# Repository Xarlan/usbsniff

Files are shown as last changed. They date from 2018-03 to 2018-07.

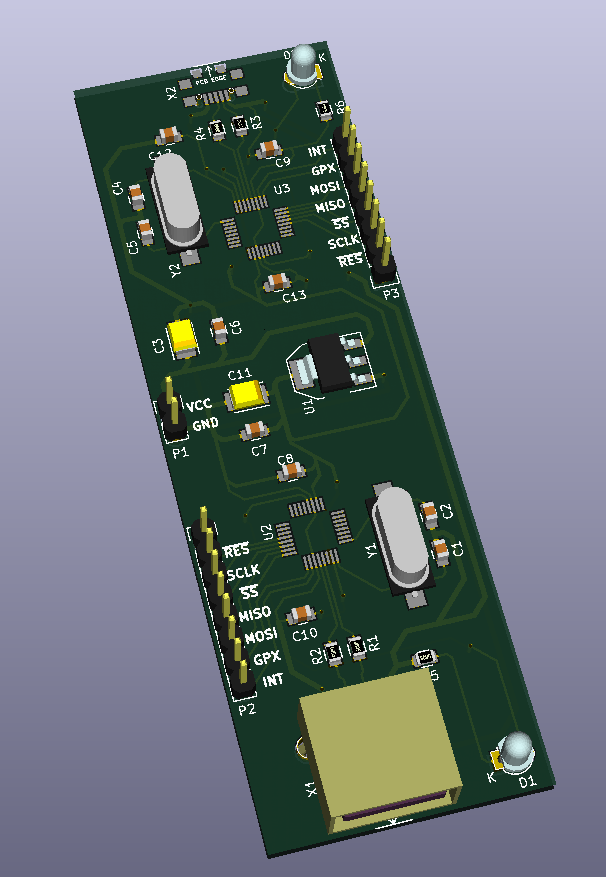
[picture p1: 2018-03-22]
prototype3.png

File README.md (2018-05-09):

# usbsniff
Develop hardware usb 2.0 sniffer

The main idea - to develop cheap hardware usb sniffer which possible to assemble at home :)

Current version based on MAX3421E

/pcb

This folder contain KiCad project of usb sniffer

## Limitation

Support follow EP:
* EP0: CONTROL (64 bytes)
* EP1: OUT, BULK or INTERRUPT
* EP2: IN, BULK or INTERRUPT
* EP3: IN, BULK or INTERRUPT

Thank you for "x8-999-github" for some good advices and idea.

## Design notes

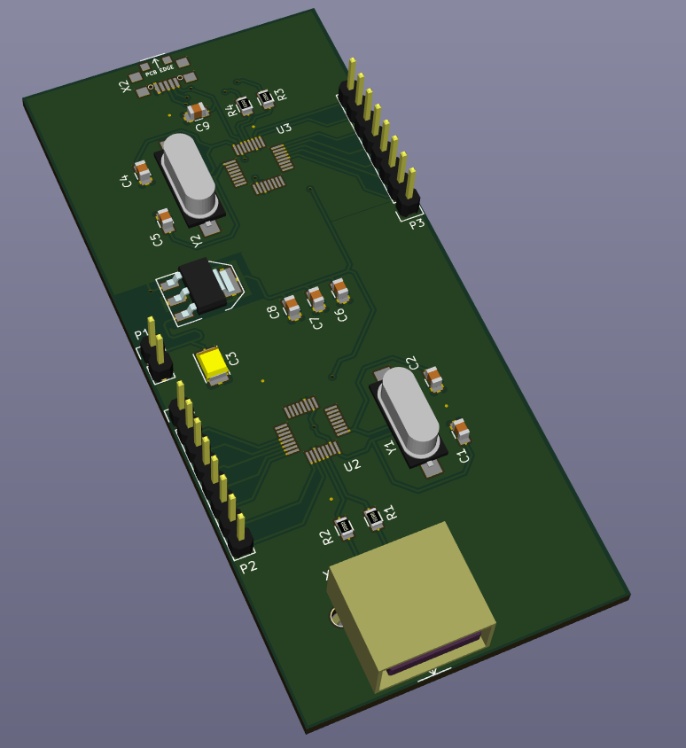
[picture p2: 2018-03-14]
prototype.png

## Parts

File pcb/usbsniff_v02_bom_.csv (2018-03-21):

Component | Description | Part | References | Value | Footprint | Quantity Per PCB | Datasheet
1 | Unpolarized capacitor | C_Small | C6 C7 C8 C13 | 0.1uF | C_0805 | 4
2 | Polarised capacitor | CP_Small | C3 C11 | 10uF | TantalC_SizeB_EIA-3528_Reflow | 2
3 | Unpolarized capacitor | C_Small | C9 C10 C12 | 1uF | C_0805 | 3
4 | Unpolarized capacitor | C_Small | C1 C2 C4 C5 | 20pF | C_0805 | 4
5 |  | LED | D1 D2 | LED | LED-3MM | 2
6 | Connector 01x02 | CONN_01X02 | P1 | CONN_01X02 | Pin_Header_Straight_1x02 | 1
7 | Connector 01x08 | CONN_01X08 | P2 P3 | CONN_01X08 | Pin_Header_Straight_1x08 | 2
8 | Resistor | R_Small | R1 R2 R3 R4 | 33 Ohm | R_0805 | 4
9 | Resistor | R | R5 R6 | 470 Ohm | R_0805 | 2
10 | Adjustable/Fixed Low Dropout Linear Regulator | AMS1117 | U1 | AMS1117 | SOT-223 | 1
11 | USB Peripheral/Host Controller with SPI Interface | MAX3421E | U2 U3 | MAX3421E | TQFP-32_5x5mm | 2
12 | socket USB type A, horizontal placement | USB_type_A | X1 | USB_type_A | USBA_1J_DS_1095_WR | 1
13 |  | micro_USB | X2 | micro_USB | micro_USB_KLS1-233-0-0-1-T | 1
14 | Two pin crystal | Crystal_Small | Y1 Y2 | 12MHz | HC49-SM | 2
Component Groups: | 14
Component Count: | 31
Fitted Components: | 31
Number of PCBs: | 1
Total components: | 31
Schematic Version:
Schematic Date:
BoM Date: | Wed 21 Mar 2018 09:01:28 PM MSK
Schematic Source: | /home/xarlan/git/usbsniff/usbsniff_v02.sch
KiCad Version: | Eeschema 4.0.2+dfsg1-stable

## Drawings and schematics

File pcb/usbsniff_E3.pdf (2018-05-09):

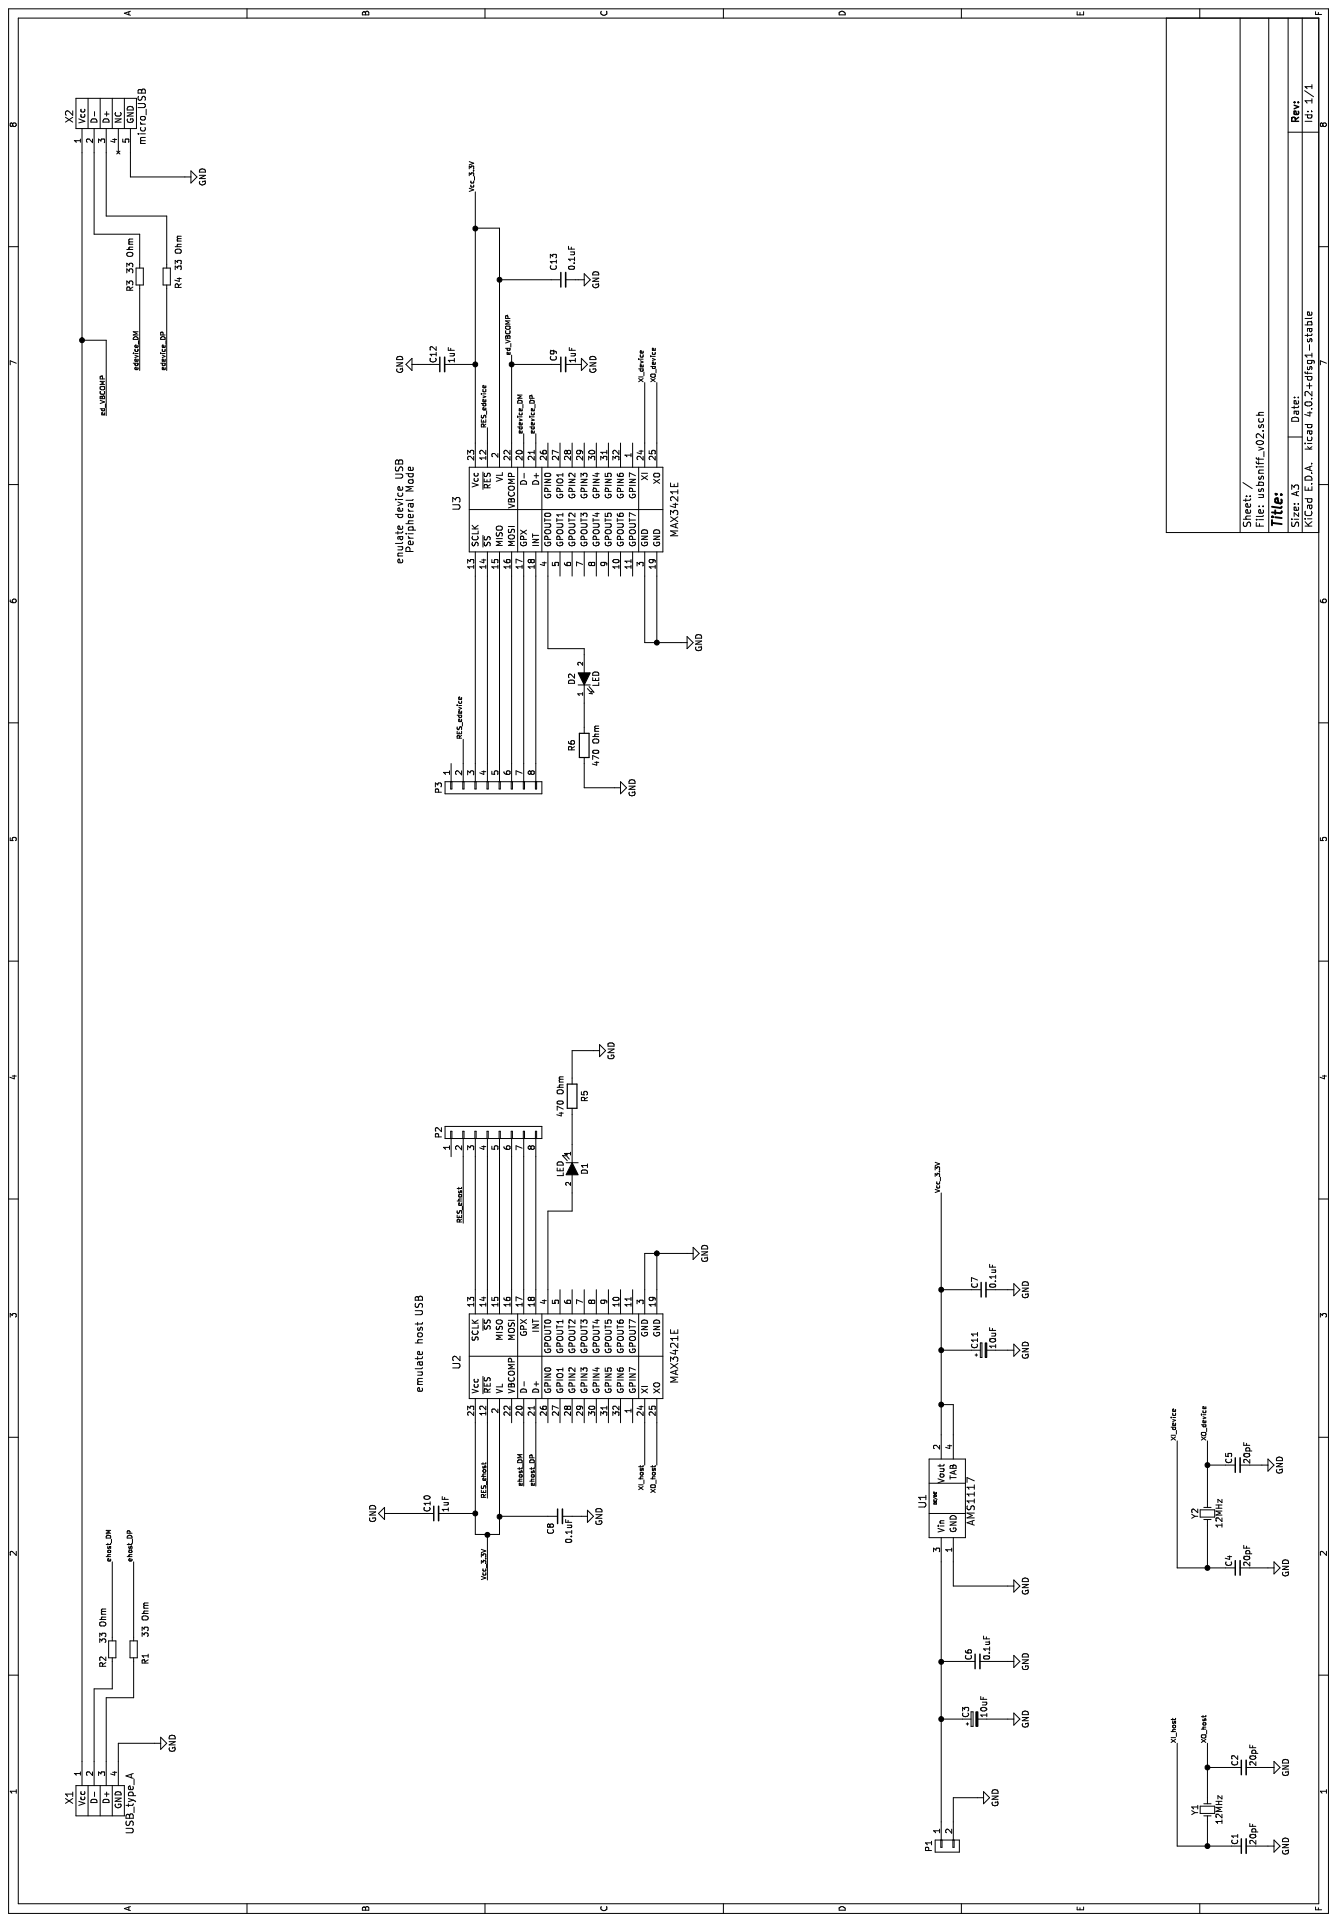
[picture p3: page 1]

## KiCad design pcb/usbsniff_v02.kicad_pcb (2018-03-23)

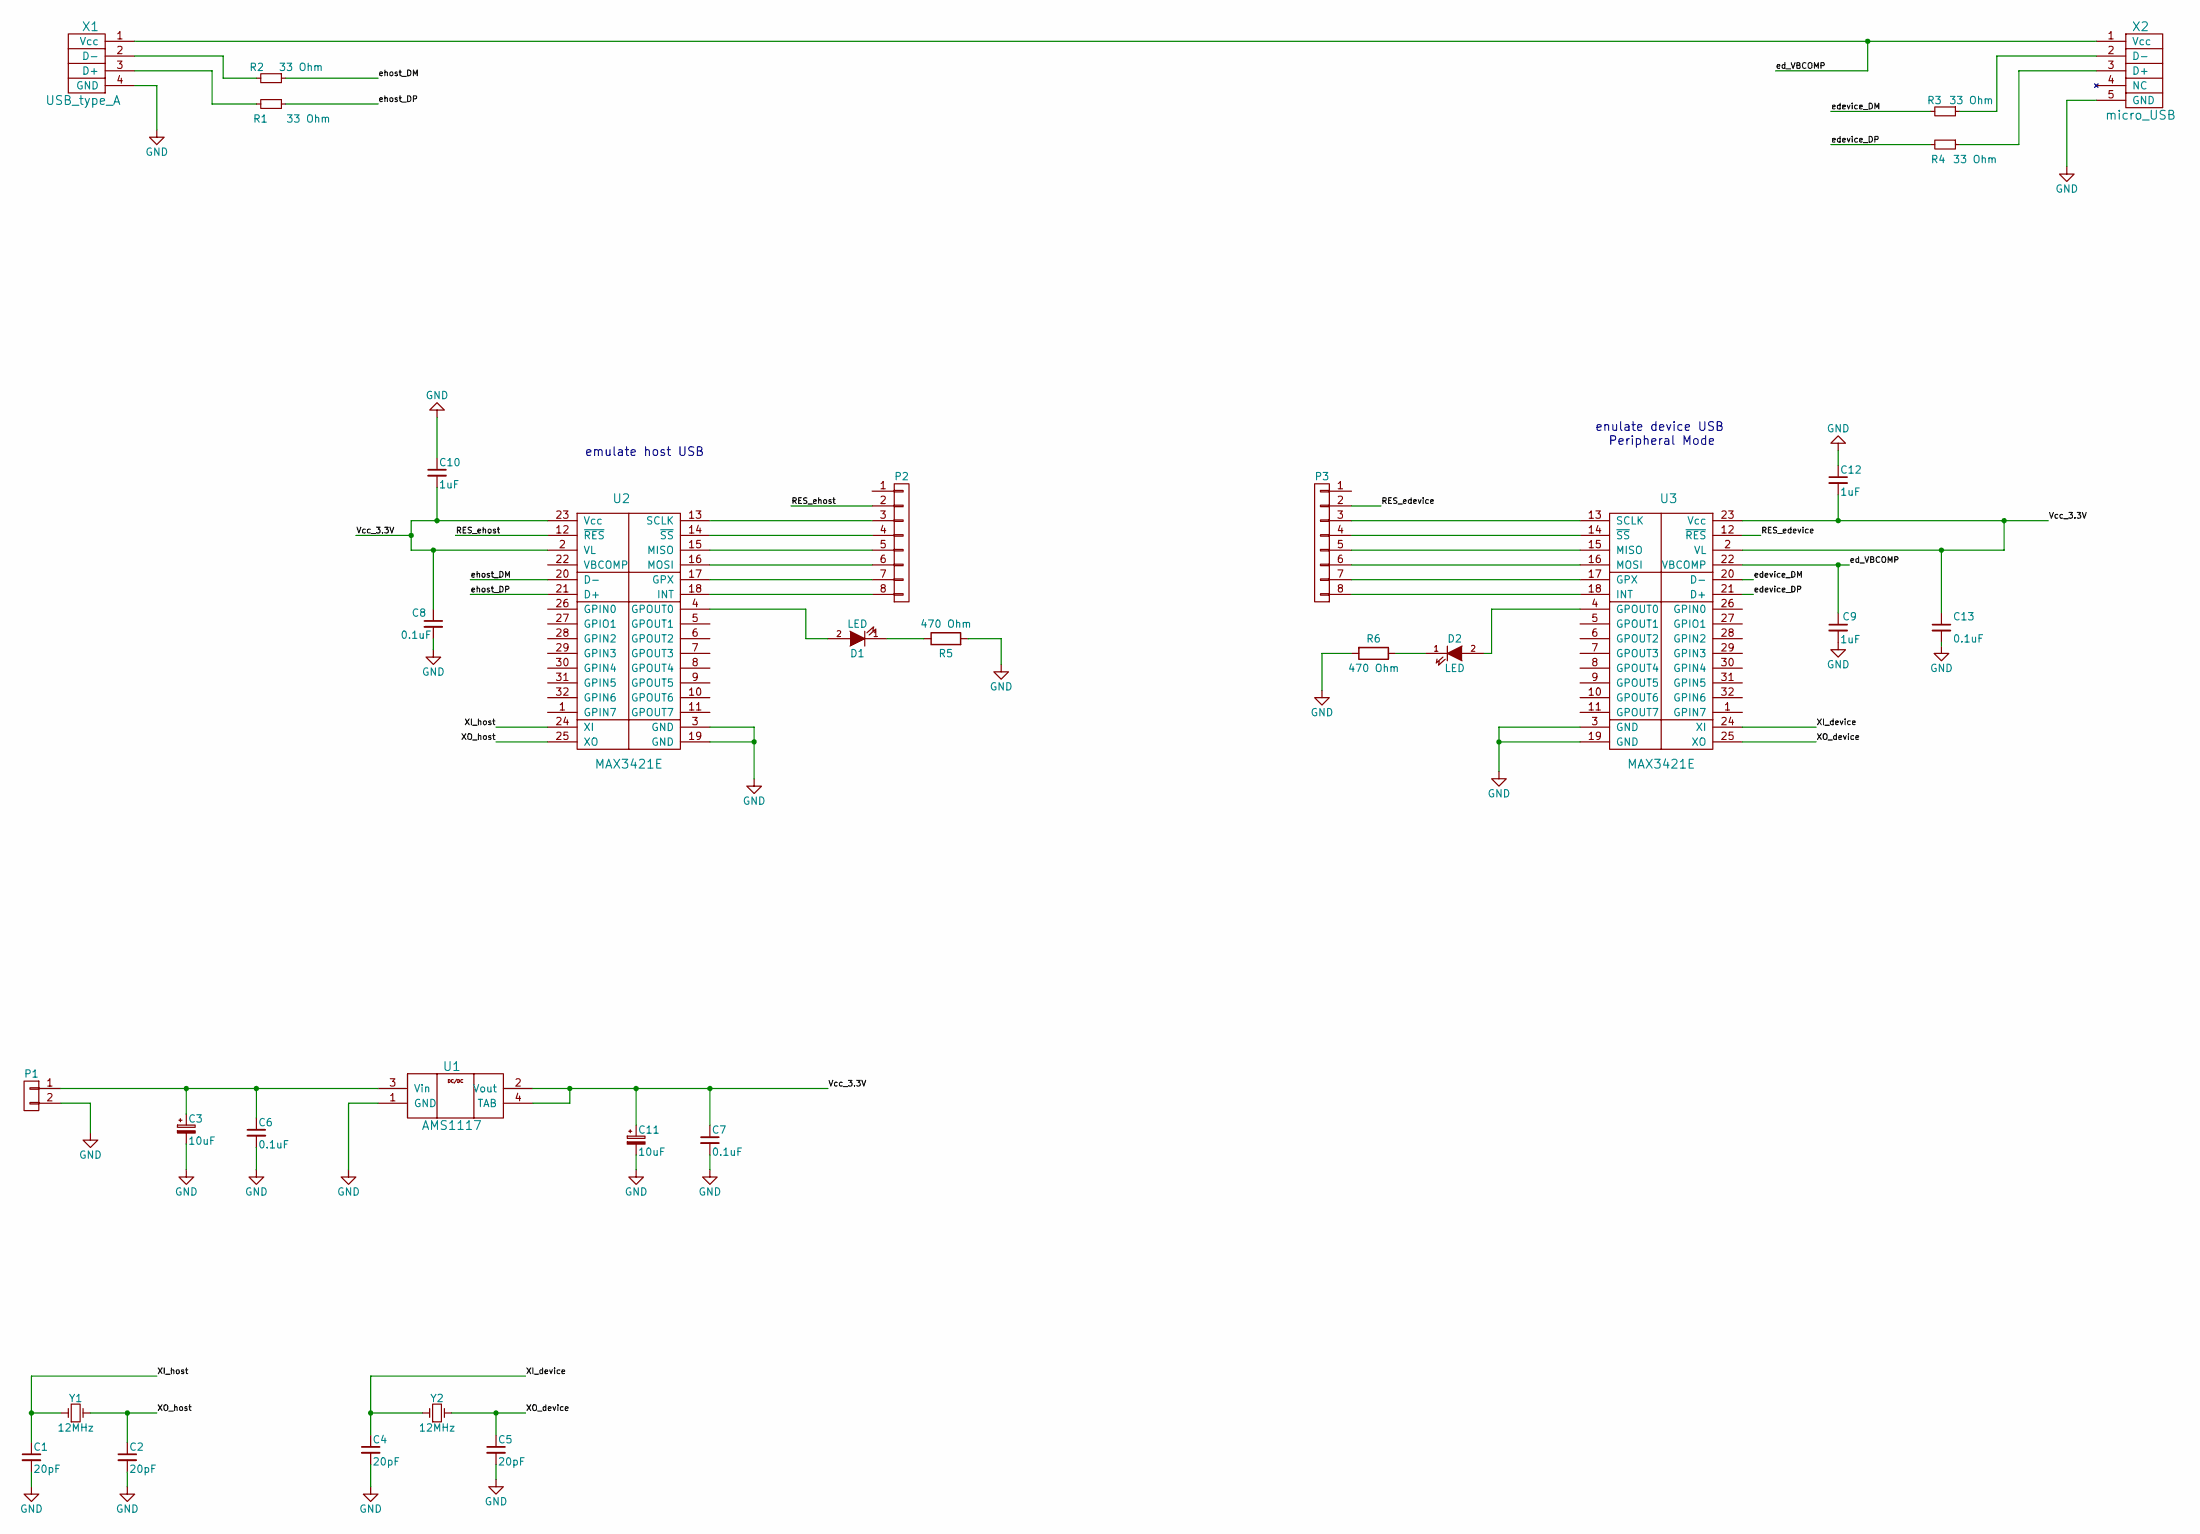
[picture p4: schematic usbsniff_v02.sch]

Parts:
C1, C2, C4, C5: 20pF; C_0805
C3, C11: 10uF; TantalC_SizeB_EIA-3528_Reflow
C6, C7, C8, C13: 0.1uF; C_0805
C9, C10, C12: 1uF; C_0805
D1, D2: LED; LED-3MM
P1: CONN_01X02; Pin_Header_Straight_1x02
P2, P3: CONN_01X08; Pin_Header_Straight_1x08
R1, R2, R3, R4: 33 Ohm; R_0805
R5, R6: 470 Ohm; R_0805
U1: AMS1117; SOT-223
U2, U3: MAX3421E; TQFP-32_5x5mm
X1: USB_type_A; USBA_1J_DS_1095_WR
X2: micro_USB; micro_USB_KLS1-233-0-0-1-T
Y1, Y2: 12MHz; HC49-SM

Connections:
/RES_edevice: P3.2, U3.12 (~RES)
/RES_ehost: P2.2, U2.12 (~RES)
/Vcc_3.3V: C7.1, C8.1, C10.2, C11.1, C12.2, C13.1, U1.2 (Vout), U1.4 (TAB), U2.2 (VL), U2.23 (Vcc), U3.2 (VL), U3.23 (Vcc)
/XI_device: C4.1, U3.24 (XI), Y2.1
/XI_host: C1.1, U2.24 (XI), Y1.1
/XO_device: C5.1, U3.25 (XO), Y2.2
/XO_host: C2.1, U2.25 (XO), Y1.2
/ed_VBCOMP: C9.1, U3.22 (VBCOMP), X1.1 (Vcc), X2.1 (Vcc)
/edevice_DM: R3.2, U3.20 (D-)
/edevice_DP: R4.2, U3.21 (D+)
/ehost_DM: R2.1, U2.20 (D-)
/ehost_DP: R1.1, U2.21 (D+)
GND: C1.2, C2.2, C3.2, C4.2, C5.2, C6.2, C7.2, C8.2, C9.2, C10.1, C11.2, C12.1, C13.2, P1.2, R5.2, R6.2, U1.1 (GND), U2.3 (GND), U2.19 (GND), U3.3 (GND), U3.19 (GND), X1.4 (GND), X2.5 (GND)
unnamed: C3.1, C6.1, P1.1, U1.3 (Vin)
unnamed: D1.1 (K), R5.1
unnamed: D1.2 (A), U2.4 (GPOUT0)
unnamed: D2.1 (K), R6.1
unnamed: D2.2 (A), U3.4 (GPOUT0)
unnamed: P2.3, U2.13 (SCLK)
unnamed: P2.4, U2.14 (~SS)
unnamed: P2.5, U2.15 (MISO)
unnamed: P2.6, U2.16 (MOSI)
unnamed: P2.7, U2.17 (GPX)
unnamed: P2.8, U2.18 (INT)
unnamed: P3.3, U3.13 (SCLK)
unnamed: P3.4, U3.14 (~SS)
unnamed: P3.5, U3.15 (MISO)
unnamed: P3.6, U3.16 (MOSI)
unnamed: P3.7, U3.17 (GPX)
unnamed: P3.8, U3.18 (INT)
unnamed: R1.2, X1.3 (D+)
unnamed: R2.2, X1.2 (D-)
unnamed: R3.1, X2.2 (D-)
unnamed: R4.1, X2.3 (D+)

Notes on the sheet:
emulate host USB
enulate device USB Peripheral Mode

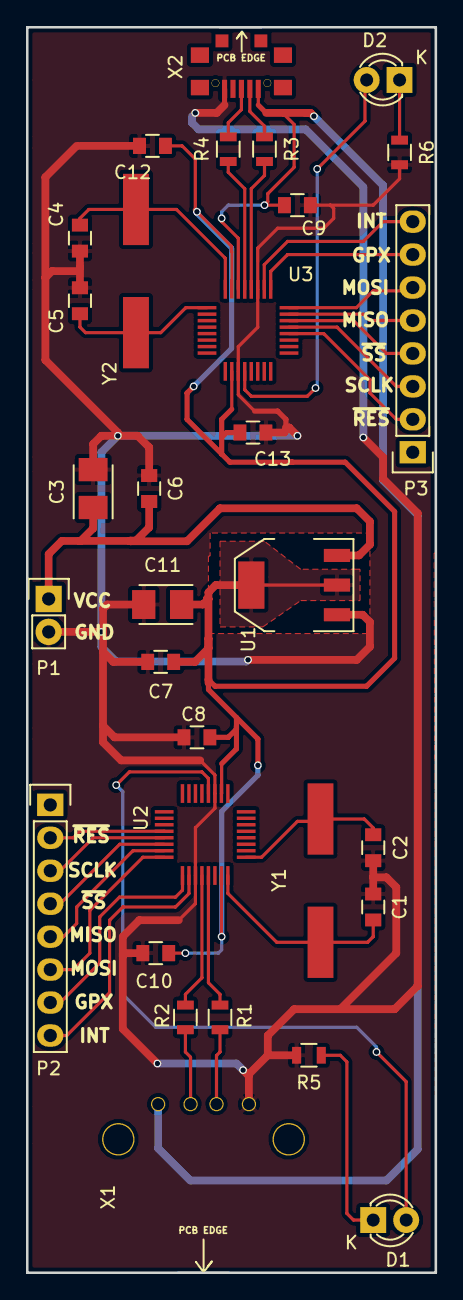
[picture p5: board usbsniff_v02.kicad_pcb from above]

Board: 2 copper layers, 31.5 x 96.0 mm, 31 parts (0 on the bottom side), 34 nets.

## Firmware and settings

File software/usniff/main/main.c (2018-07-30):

/*
This Source Code Form is subject to the terms of the Mozilla Public
License, v. 2.0. If a copy of the MPL was not distributed with this
file, You can obtain one at http://mozilla.org/MPL/2.0/.
*/

#include <stdio.h>
#include <string.h>
#include "freertos/FreeRTOS.h"
#include "freertos/task.h"
#include "esp_system.h"
#include "esp_spi_flash.h"
#include "driver/spi_master.h"

#include "usbconf.h"
#include "max3421e.h"


void send_msg_spi(spi_device_handle_t hwnd_spi, const uint8_t data);
void send_msg_spi2(spi_device_handle_t hwnd_spi, const uint8_t *data, int len_tx_msg);

void rxtx_spi(spi_device_handle_t hwnd_spi, const uint8_t *data, int len_tx_msg);


void vBlinkLed(void * pvParameters);


void app_main()
{
	printf("Hardware USB sniffer\n");

	spi_device_handle_t hwnd_usb_host;				// handle of SPI where connected MAX3421E in "usb host mode"
	spi_bus_config_t usb_host_buscfg;				// config SPI bus
	spi_device_interface_config_t usb_host_devcfg;	// config attached device (MAX3421)

	spi_device_handle_t hwnd_usb_device;				// handle of SPI where connected MAX3421E in "usb device mode"
	spi_bus_config_t usb_device_buscfg;					// config SPI bus
	spi_device_interface_config_t usb_device_devcfg;	// config attached device MAX3421 on "usb device mode"

	init_max3421e_host(&hwnd_usb_host, &usb_host_buscfg, &usb_host_devcfg);
	init_max3421e_device(&hwnd_usb_device, &usb_device_buscfg, &usb_device_devcfg);


	static xHwndSpi hwndMAX3421E;

	hwndMAX3421E.spi_host = hwnd_usb_host;
	hwndMAX3421E.spi_device = hwnd_usb_device;

	BaseType_t xReturned;

	xReturned = xTaskCreate(vBlinkLed,
							"BlinkLed",
							1536,						// stack size
							(void*)	&hwndMAX3421E,
							1,
							NULL);

	if ( xReturned == pdPASS)
	{
		printf("BlinkLed was created\n");
	}

}


// Init spi bus on ESP32
// ESP32 <---spi---> MAX3421 in host mode
void init_max3421e_host(spi_device_handle_t *hwnd_spi,
						   spi_bus_config_t *buscfg,
						   spi_device_interface_config_t *devcfg)
{
	// the configuration of SPI bus
	buscfg->mosi_io_num 	= USB_HOST_PIN_MOSI;
	buscfg->miso_io_num 	= USB_HOST_PIN_MISO;
	buscfg->sclk_io_num 	= USB_HOST_PIN_CLK;
	buscfg->quadwp_io_num 	= -1;
	buscfg->quadhd_io_num 	= -1;
	buscfg->max_transfer_sz = 0;
	buscfg->flags			= SPICOMMON_BUSFLAG_MASTER;

	// Initialize the SPI bus
	ESP_ERROR_CHECK(spi_bus_initialize(HSPI_HOST, buscfg, 0));
//	ESP_ERROR_CHECK(spi_bus_initialize(HSPI_HOST, buscfg, 1));
	printf("HSPI_HOST was successfully initialized\n");

	// the configuration of attached device (MAX3421 on "usb host mode")
	devcfg->address_bits		= 0;
	devcfg->command_bits		= 8;
	devcfg->dummy_bits			= 0;
	devcfg->mode				= 0;             		 //SPI mode 0
	devcfg->duty_cycle_pos		= 0;
	devcfg->cs_ena_posttrans	= 0;
	devcfg->cs_ena_pretrans		= 0;
	devcfg->clock_speed_hz		= SPI_CLK_MAX3421E_HOST;    		//Clock out
	devcfg->spics_io_num		= USB_HOST_PIN_CS;     	//CS pin
	devcfg->flags				= 0;
	devcfg->queue_size			= 3;              		//We want to be able to queue 7 transactions at a time
	devcfg->pre_cb				= NULL;
	devcfg->post_cb				= NULL;

	// Attach the MAX3421E (usb host mode) the SPI bus
	ESP_ERROR_CHECK(spi_bus_add_device(HSPI_HOST, devcfg, hwnd_spi));
	printf("MAX3421E in 'host' mode was successfully added\n");
}


// Init spi bus on ESP32
// ESP32 <---spi---> MAX3421 in device mode
void init_max3421e_device(spi_device_handle_t *hwnd_spi,
						spi_bus_config_t *buscfg,
						spi_device_interface_config_t *devcfg )
{
	buscfg->sclk_io_num 		= USB_DEVICE_CLK;
	buscfg->mosi_io_num 		= USB_DEVICE_MOSI;
	buscfg->miso_io_num 		= USB_DEVICE_MISO;
	buscfg->quadwp_io_num 		= -1;
	buscfg->quadhd_io_num 		= -1;
	buscfg->max_transfer_sz 	= 0;
	buscfg->flags				= SPICOMMON_BUSFLAG_MASTER;

	// Initialize the SPI bus
	ESP_ERROR_CHECK(spi_bus_initialize(VSPI_HOST, buscfg, 0));
//	ESP_ERROR_CHECK(spi_bus_initialize(VSPI_HOST, buscfg, 1));
	printf("VSPI_HOST was successfully initialized\n");

	// the configuration of attached device (MAX3421 on "usb device mode"
	devcfg->address_bits		= 0;
	devcfg->command_bits		= 8;
	devcfg->dummy_bits			= 0;
	devcfg->mode				= 0;              //SPI mode 0
	devcfg->duty_cycle_pos		= 0;
	devcfg->cs_ena_posttrans	= 0;
	devcfg->cs_ena_pretrans		= 0;
	devcfg->clock_speed_hz		= SPI_CLK_MAX3421E_DEVICE;    //Clock out
	devcfg->spics_io_num		= USB_DEVICE_CS;   //CS pin
	devcfg->flags				= 0;
	devcfg->queue_size			= 3;              //We want to be able to queue 7 transactions at a time
	devcfg->pre_cb				= NULL;
	devcfg->post_cb				= NULL;

	// Attach the MAX3421E (usb device mode) the SPI bus
	ESP_ERROR_CHECK(spi_bus_add_device(VSPI_HOST, devcfg, hwnd_spi));
	printf("MAX3421E in 'device' mode was successfully added\n");

}


void rxtx_spi(spi_device_handle_t hwnd_spi, const uint8_t *data, int len_tx_msg)
{
    spi_transaction_t msg_spi;

		msg_spi.addr		= 0;
		msg_spi.cmd			= 0;
		msg_spi.flags		= 0;
		msg_spi.length		= 8*len_tx_msg;
		msg_spi.tx_buffer	= data;
		msg_spi.rx_buffer	= NULL;
		msg_spi.rxlength	= 0;
		msg_spi.user		= NULL;

    ESP_ERROR_CHECK(spi_device_transmit(hwnd_spi, &msg_spi));
}


void send_msg_spi(spi_device_handle_t hwnd_spi, const uint8_t data)
{

    spi_transaction_t msg_spi;

		msg_spi.addr		= 0;
		msg_spi.cmd			= 0xA2;
		msg_spi.flags		= 0;
		msg_spi.length		= 8;
		msg_spi.tx_buffer	= &data;
		msg_spi.rx_buffer	= NULL;
		msg_spi.user		= NULL;

    ESP_ERROR_CHECK(spi_device_transmit(hwnd_spi, &msg_spi));
}


void send_msg_spi2(spi_device_handle_t hwnd_spi, const uint8_t *data, int len_tx_msg)
{
    spi_transaction_t msg_spi;

		msg_spi.addr		= 0;
		msg_spi.cmd			= 0;
		msg_spi.flags		= 0;
		msg_spi.length		= 8*len_tx_msg;
		msg_spi.tx_buffer	= data;
		msg_spi.rx_buffer	= NULL;
		msg_spi.rxlength	= 0;
		msg_spi.user		= NULL;

    ESP_ERROR_CHECK(spi_device_transmit(hwnd_spi, &msg_spi));
}


void max3421e_rx_tx(spi_device_handle_t hwnd_spi, max3421e_msg *data)
{
    spi_transaction_t msg_spi;

		msg_spi.addr		= 0;
		msg_spi.cmd			= data->cmd > 0 ? data->cmd : 0;
		msg_spi.flags		= 0;
		msg_spi.length		= (data->tx_len > data->rx_len) ? 8 * data->tx_len : 8 * data->rx_len;
		msg_spi.tx_buffer	= (data->cmd & 0x2) == 0 ? NULL : data->tx_data;
		msg_spi.rx_buffer	= (data->rx_len) != 0 ? data->rx_data : NULL;
		msg_spi.rxlength	= data->rx_len;
		msg_spi.user		= NULL;

    ESP_ERROR_CHECK(spi_device_transmit(hwnd_spi, &msg_spi));
}

void max3421e_rx_tx2(spi_device_handle_t hwnd_spi, max3421e_msg *data)
{
    spi_transaction_t msg_spi;

		msg_spi.addr		= 0;
		msg_spi.cmd		= 0;
		msg_spi.flags		= 0;
		msg_spi.length		= (data->tx_len > data->rx_len) ? 8 * data->tx_len : 8 * data->rx_len;
		msg_spi.tx_buffer	= data->rw ? data->tx_data : NULL;
		msg_spi.rx_buffer	= (data->rx_len) != 0 ? data->rx_data : NULL;
		msg_spi.rxlength	= data->rx_len;
		msg_spi.user		= NULL;

    ESP_ERROR_CHECK(spi_device_transmit(hwnd_spi, &msg_spi));
}


/*
 *  This is test Task for blink led
 */
void vBlinkLed(void * pvParameters)
{
	static xHwndSpi *pxTaskParam;
	pxTaskParam = (xHwndSpi*) pvParameters;

	max3421e_msg *blink_on, *blink_off;


		blink_on = malloc(sizeof(max3421e_msg));
		if ( blink_on == NULL )
		{
			printf("	***\n");
			printf("Not enough memory\n");
			printf("	***\n");

		}

		blink_on->cmd = IOPINS1 | DIR_WR;
		blink_on->tx_data[0] = 0x1;
		blink_on->tx_len = 1;
		blink_on->rx_len = 0;

		blink_off = malloc(sizeof(max3421e_msg));
		if ( blink_off == NULL )
		{
			printf("	***\n");
			printf("Not enough memory for blink_off\n");
			printf("	***\n");

		}

		blink_off->cmd = IOPINS1 | DIR_WR;
		blink_off->tx_data[0] = 0x0;
		blink_off->tx_len = 1;
		blink_off->rx_len = 0;

		while ( 1 )
		{

			vTaskDelay(500 / portTICK_PERIOD_MS);
			max3421e_rx_tx(pxTaskParam->spi_device, blink_off);
			max3421e_rx_tx(pxTaskParam->spi_host, blink_on);


			vTaskDelay(500 / portTICK_PERIOD_MS);
			max3421e_rx_tx(pxTaskParam->spi_device, blink_on);
			max3421e_rx_tx(pxTaskParam->spi_host, blink_off);

		}

		vTaskDelete(NULL);

}

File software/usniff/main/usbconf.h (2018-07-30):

/*
This Source Code Form is subject to the terms of the Mozilla Public
License, v. 2.0. If a copy of the MPL was not distributed with this
file, You can obtain one at http://mozilla.org/MPL/2.0/.
*/

/*
 * usbconf.h
 *
 *  Created on: Jul 15, 2018
 *      Author: lem
 */

#ifndef MAIN_USBCONF_H_
#define MAIN_USBCONF_H_

// PINS which connected to MCU_spi <-> MAX3421 in host mode
#define USB_HOST_PIN_CLK  	25
#define USB_HOST_PIN_MOSI 	26
#define USB_HOST_PIN_MISO 	32
#define USB_HOST_PIN_CS   	33

// PINS which connected to MCU_spi <-> MAX3421 in device mode
#define USB_DEVICE_CLK   	21
#define USB_DEVICE_MOSI 	22
#define USB_DEVICE_MISO 	19
#define USB_DEVICE_CS   	23

#define MAX_BUF_USB_TX		64
#define MAX_BUF_USB_RX		64

#define SPI_CLK_MAX3421E_DEVICE		18*1000*1000			// attached to VSPI
#define SPI_CLK_MAX3421E_HOST		18*1000*1000			// attached to HSPI


typedef struct {
    			uint8_t 	cmd;
    			uint8_t		tx_data[MAX_BUF_USB_TX];
    			uint16_t 	tx_len;
    			uint8_t 	rx_data[MAX_BUF_USB_RX];
    			uint16_t 	rx_len;
} max3421e_msg;

typedef struct {
			uint8_t		reg;
			uint8_t		rw;
			uint8_t		tx_data[MAX_BUF_USB_TX];
    			uint16_t 	tx_len;
    			uint8_t 	rx_data[MAX_BUF_USB_RX];
    			uint16_t 	rx_len;
} MAX3421Emsg;

typedef struct {
	spi_device_handle_t spi_host;
	spi_device_handle_t spi_device;
} xHwndSpi;


/*
 * Configure SPI bus and attach MAX3421E (usb-host mode) to ESP32 via SPI
 */

void init_max3421e_host(spi_device_handle_t *hwnd_spi,
						spi_bus_config_t *buscfg,
						spi_device_interface_config_t *devcfg );


/*
 * Configure SPI bus and attach MAX3421E (usb-device mode) to ESP32 via SPI
 */

void init_max3421e_device(spi_device_handle_t *hwnd_spi,
						spi_bus_config_t *buscfg,
						spi_device_interface_config_t *devcfg );

/*
 * Transmit and receive data from MAX3421E via SPI bus
 */
//void max3421e_rx_tx(spi_device_handle_t hwnd_spi, const max3421e_msg *data);
void max3421e_rx_tx(spi_device_handle_t hwnd_spi, max3421e_msg *data);



#endif /* MAIN_USBCONF_H_ */

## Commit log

2018-03-14 have done schematic and pcb based on MAX3421
    [usbsniff_v02.kicad_pcb, usbsniff_v02.sch]
2018-03-14 add picture of prototype
2018-03-21 add LED, redesign pcb
    [usbsniff_v02.kicad_pcb, usbsniff_v02.sch, usbsniff_v02_bom_.csv]
2018-03-22 redesign wires
    [usbsniff_v02.kicad_pcb]
2018-03-23 fix polygon around ams1117
    [usbsniff_v02.kicad_pcb]
2018-07-29 create test task BlinkLed to check pcb
